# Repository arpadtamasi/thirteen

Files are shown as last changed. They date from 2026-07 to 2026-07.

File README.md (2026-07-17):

# thirteen

**A keyboard has 104 keys. When agents do the typing, you need thirteen:
status, approval, direction.**

An open-source, firmware-agnostic agent macropad: 13 mechanical keys, a
rotary encoder, a joystick, and per-key RGB that shows what your AI agents
are doing right now — thinking, running, waiting for you, done. Press a key
to approve. Flick the stick to steer.

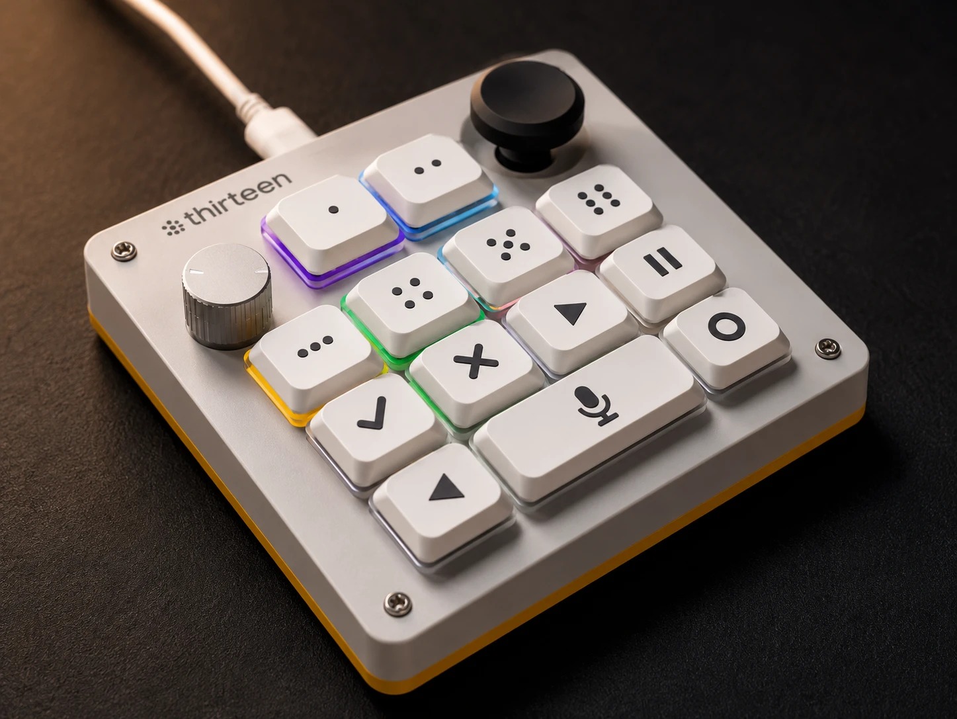
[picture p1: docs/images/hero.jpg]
thirteen — white colorway concept render


*AI-generated concept render of the actual design in this repo — key LEDs
in the daemon's default state colors: violet = thinking, blue = running,
amber = waiting, green = done; the edge ring glows with whichever agent
needs attention most. No physical build yet — the raw CAD geometry it's
based on is in [docs/images/cad-assembled-white.png](docs/images/cad-assembled-white.png),
rendered straight from `hardware/case/thirteen_case.scad`.*

## Why

OpenAI and Work Louder make a lovely version of this idea, the
[Codex Micro](https://openai.com/supply/co-lab/work-louder/): 13 keys,
encoder, joystick, $230 — and its agent features only work with one
vendor's desktop app.

thirteen is the DIY answer:

| | Codex Micro | thirteen |
|---|---|---|
| price | $230 | ~€30 in parts |
| keys / encoder / joystick | 13 / yes / yes | 13 / yes / yes |
| per-key RGB agent status | yes | yes |
| works with | Codex via ChatGPT desktop | anything (adapter pattern) |
| firmware | closed | this repo |
| case | CNC polycarbonate + aluminium | your 3D printer |

The core design principle: **the hardware knows nothing about any specific
agent.** The device is a plain USB HID keyboard plus a serial port speaking
newline-delimited JSON. All intelligence lives in a host-side daemon with
swappable adapters — Claude Code today, anything tomorrow, no reflash.

## Architecture

```
┌────────────┐ hooks  ┌──────────────────────┐   NDJSON    ┌──────────────┐
│ Claude Code├───────▶│                      │ over serial │   thirteen   │
└────────────┘        │    thirteen-host     │   115200 8N1 │  (ESP32-S3)  │
┌────────────┐ NDJSON │                      │             │              │
│ anything   ├───────▶│  adapters ──┐        │──── LEDs ──▶│ 19× SK6812   │
│ (stdin)    │        │  claude_code│ daemon │             │ 13× Choc     │
└────────────┘        │  generic_st…│  ────  │◀── events ──│ EC11 encoder │
┌────────────┐        │  demo      ─┘        │             │ 2-axis stick │
│ your agent ├───────▶│  config: one TOML    │             └──────┬───────┘
└────────────┘        └──────────────────────┘                    │ USB HID
                                                                  ▼
                                                        keystrokes (F13–F24)
                                                        straight to the OS
```

Two independent paths, by design:

- **Status path** (needs the daemon): adapter sees agent activity → daemon
  maps agent→key → LED shows state. Violet pulse = thinking, blue pulse =
  running, amber blink = **waiting for you**, green = done.
- **Action path** (works without any software): keys are a real HID
  keyboard typing F13–F24. Bind them in your terminal — approve, reject,
  interrupt — even if the daemon is down.

## Quickstart

**Have hardware?** Follow [docs/build-guide.md](docs/build-guide.md).
**Building from scratch?** [hardware/BOM.md](hardware/BOM.md) (~€30, with
shop links and a copy-paste [agent shopping prompt](hardware/BOM.md#agent-shopping-prompt)),
[hardware/WIRING.md](hardware/WIRING.md), printable case in
[hardware/case/](hardware/case/).

```sh
# 1. firmware (PlatformIO)
cd firmware && pio run -t upload && pio run -t uploadfs

# 2. host daemon
cd ../host && pip install -e .
cp config/thirteen.example.toml thirteen.toml   # set your port: /dev/ttyACM0 or COM3
thirteen-host

# 3. smoke test — a key should blink amber:
echo '{"agent_id":"hi","state":"waiting"}' | thirteen-host
```

Claude Code integration is a five-line hooks snippet:
[docs/adapter-guide.md](docs/adapter-guide.md). Key bindings, the voice
talk bar, and daily workflow: [docs/user-guide.md](docs/user-guide.md).

## Adapters

| adapter | drives it | status |
|---|---|---|
| `claude_code` | Claude Code hooks; multi-session, one key per session | ✅ shipped |
| `generic_stdin` | NDJSON on stdin — shell scripts, Codex CLI, n8n, CI | ✅ shipped |
| `demo` | nothing; cycles states for testing | ✅ shipped |
| yours | ~50 lines of Python: [docs/adapter-guide.md](docs/adapter-guide.md) | 🙋 PRs welcome |

## Repo map

```
firmware/   ESP32-S3 PlatformIO project (USB HID + CDC, LittleFS keymap)
protocol/   PROTOCOL.md — the NDJSON serial contract, versioned
host/       thirteen-host Python daemon + adapters
hardware/   BOM, wiring, parametric OpenSCAD case
docs/       build guide, user guide (bindings + voice), adapter guide
```

## Contributing

Small repo, sharp edges welcome — see [CONTRIBUTING.md](CONTRIBUTING.md).
Especially wanted: adapters for other agents, hw-test reports (grep for
`TODO(hw-test)`), case remixes.

## License

[MIT](LICENSE).

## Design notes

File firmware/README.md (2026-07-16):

# thirteen firmware

PlatformIO project for the ESP32-S3. Builds a USB composite device:
HID keyboard + CDC serial.

## Build & flash

```sh
pio run                          # build (default env: esp32-s3-devkitc-1)
pio run -t upload                # flash over USB
pio run -t uploadfs              # upload data/keymap.json to LittleFS
pio device monitor               # watch the NDJSON event stream
```

For an ESP32-S3 SuperMini board:

```sh
pio run -e supermini -t upload
```

The SuperMini has fewer pins broken out; its pin mapping lives in
`src/pins.h` behind the `SUPERMINI` define. Check it against your specific
board — SuperMini clones vary.

If the board doesn't enumerate after flashing, unplug/replug USB (switching
to the TinyUSB stack requires a cold restart of the USB connection).

## Layout

| file | what |
|---|---|
| `src/main.cpp`| entry point, serial protocol, HID output |
| `src/pins.h`  | GPIO assignment (both boards) |
| `src/input.*` | key debounce, EC11 decode, joystick gestures |
| `src/leds.*`  | SK6812 chain, solid/pulse/blink modes |
| `src/keymap.*`| LittleFS-persisted keymap, editable over serial  |
| `data/` | default keymap shipped to LittleFS via uploadfs  |

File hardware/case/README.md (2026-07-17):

# Case

Parametric OpenSCAD case: a top plate with Choc cutouts and a bottom shell
with a USB-C opening, screwed together with four M3 heat-set inserts.

## Export STLs

With [OpenSCAD](https://openscad.org/) installed:

```sh
openscad -D 'part="plate"' -o thirteen_plate.stl thirteen_case.scad
openscad -D 'part="shell"' -o thirteen_shell.stl thirteen_case.scad
```

Or in the GUI: open `thirteen_case.scad`, pick the part in the Customizer,
press F6 (render), then File → Export → STL.

## Render a preview image

`part="display"` is a non-printable assembled preview — keycaps with
legend icons (session dots 1-5, approve / reject / run / pause / stop,
prev / next / clear), encoder knob, thumbstick and per-key LED glow in
the daemon's default state colors. Render it in preview mode (no
`--render`, so colors show):

```sh
openscad -D 'part="display"' --imgsize=1920,1440 \
  --colorscheme='Tomorrow Night' --camera=51,46,8,45,0,318,240 \
  -o thirteen.png thirteen_case.scad
```

Options: `-D 'display_style="white"'` for the white colorway,
`-D show_icons=false` for blank caps.

## Print settings

- Plate: 0.2mm layers, 4+ perimeters, print flat, no supports. PETG or ABS
  preferred — Choc clips stress PLA over time.
- Shell: same, USB opening prints fine without supports at 45° bridging.
- Push M3 inserts into the shell bosses with a soldering iron at ~220°C.

## Tuning

Everything is a parameter at the top of the file. The ones you'll most
likely touch:

| parameter | default | change when |
|---|---|---|
| `switch_cutout` | 13.8 | your printer over/under-extrudes (try ±0.1) |
| `key_pitch_x/y` | 18.0 / 17.0 | using MX switches (19.05 / 19.05, cutout 14.0) |
| `shell_inner_height` | 13.0 | your wiring is tidier/messier than average |
| `usb_z` | 4.0 | your MCU sits at a different height — TODO(hw-test) |
| `joy_hole_d` | 24.0 | different joystick module |

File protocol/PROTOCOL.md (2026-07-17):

# thirteen serial protocol — v1

Newline-delimited JSON (NDJSON) over USB CDC serial, **115200 baud**, UTF-8.
One JSON object per line, terminated by `\n`. No line may exceed 1024 bytes
(a full `keymap_set` with text macros approaches this; keep macros short).

Every message carries a version field `"v": 1`. Receivers MUST ignore
messages with a higher major version than they support, and MUST ignore
unknown fields (forward compatibility).

Message type is in `"t"`.

## Transport

- The device enumerates as a USB composite device: HID keyboard + CDC serial.
- The HID interface types keystrokes directly (no host software needed for
  basic macro use). The CDC interface carries this protocol.
- On (re)connect the device sends `hello`. The host SHOULD wait for `hello`
  (or send `ping`) before assuming the link is up.

## Host → Device

### `ping`

```json
{"v": 1, "t": "ping"}
```

Device replies with `pong`.

### `led` — set the state of one key LED (or all)

```json
{"v": 1, "t": "led", "key": 4, "color": "#00FF88", "mode": "pulse"}
```

| field | type | notes |
|---|---|---|
| `key` | int | 0–12 = key LEDs, 13–18 = edge-glow segments, `-1` = every LED, `-2` = the edge ring as a group |
| `color` | string | `#RRGGBB` hex |
| `mode`  | string | `"solid"`, `"pulse"` (slow breathe), `"blink"` (hard on/off), `"off"` |

Device replies with `ack`.

### `keymap_set` — replace the stored keymap

```json
{"v": 1, "t": "keymap_set", "map": {"keys": [{"type": "key", "code": "F13"}, ...]}}
```

The `map` object is persisted to LittleFS (`/keymap.json`) and applied
immediately — no reflash required. See **Keymap format** below.
Device replies with `ack` (with `"ok": false` and an `"err"` string if the
map fails validation).

### `keymap_get` — read the current keymap

```json
{"v": 1, "t": "keymap_get"}
```

Device replies with `{"v": 1, "t": "keymap", "map": {...}}`.

## Device → Host

### `hello` — sent once on boot / USB reconnect

```json
{"v": 1, "t": "hello", "fw": "0.1.0", "proto": 1, "keys": 13, "edge": 6}
```

`edge` is the number of edge-glow LEDs after the key LEDs on the chain
(0 if the build has none).

### `key` — key press / release

```json
{"v": 1, "t": "key", "key": 7, "act": "down"}
```

`act` is `"down"` or `"up"`. Sent **in addition to** any HID output the
keymap produces for that key; keys mapped as `"none"` produce only this
event.

### `enc` — rotary encoder rotation

```json
{"v": 1, "t": "enc", "delta": 1}
```

`delta` is a signed integer: positive = clockwise. Multiple detents within
one poll interval are coalesced.

### `enc_btn` — encoder push

```json
{"v": 1, "t": "enc_btn", "act": "down"}
```

### `joy` — joystick gesture

```json
{"v": 1, "t": "joy", "dir": "up"}
```

`dir` is one of `"up"`, `"down"`, `"left"`, `"right"` (emitted once when the
stick leaves the deadzone in that direction; re-armed when it returns to
center) or `"press"` / `"release"` for the stick button.

### `ack`

```json
{"v": 1, "t": "ack", "of": "led", "ok": true}
{"v": 1, "t": "ack", "of": "keymap_set", "ok": false, "err": "bad key code"}
```

### `pong`

```json
{"v": 1, "t": "pong", "fw": "0.1.0", "proto": 1}
```

## Keymap format

The keymap is a JSON object stored on the device at `/keymap.json`:

```json
{
  "keys": [
    {"type": "key",  "code": "F13"},
    {"type": "key",  "code": "ENTER"},
    {"type": "text", "value": "yes\n"},
    {"type": "none"},
    ...13 entries total...
  ],
  "enc": {"cw": {"type": "key", "code": "VOL_UP"},
          "ccw": {"type": "key", "code": "VOL_DOWN"},
          "btn": {"type": "none"}}
}
```

Entry types:

| type | fields  | behaviour |
|---|---|---|
| `key`  | `code`  | sends a single HID keycode (see codes below) |
| `text` | `value` | types the string verbatim (`\n` allowed) |
| `none` | — | no HID output; the serial event is still emitted |

Recognised `code` values: `F1`–`F24`, `ENTER`, `ESC`, `TAB`, `SPACE`,
`BACKSPACE`, `UP`, `DOWN`, `LEFT`, `RIGHT`, `PAGE_UP`, `PAGE_DOWN`,
`VOL_UP`, `VOL_DOWN`, `MUTE`, and any single ASCII character (`"y"`, `"1"`).

`F13`–`F24` are the recommended defaults: real HID codes that no ordinary
keyboard emits, so they are safe to bind globally on the host side.

## Versioning

- `proto` in `hello`/`pong` is the protocol major version implemented by the
  firmware.
- Additive changes (new fields, new message types) do not bump the version.
- Breaking changes bump `v`/`proto`; a host seeing a higher `proto` than it
  knows SHOULD warn and fall back to `ping`/`key` events only.

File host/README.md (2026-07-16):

# thirteen-host

Python daemon that bridges the thirteen macropad to your agents.

```sh
pip install -e .                 # from this directory
cp config/thirteen.example.toml thirteen.toml
# edit thirteen.toml: set your serial port (/dev/ttyACM0, COM3, ...)
thirteen-host
```

Quick LED test without any agent: enable `[adapters.demo]` in the config
and watch the bottom row cycle through the state colors.

Quick test from a shell (generic_stdin adapter):

```sh
echo '{"agent_id":"hello","state":"waiting"}' | thirteen-host
```

Claude Code integration: install the `thirteen-hook` script into your hooks
(see `docs/adapter-guide.md`), then just use Claude Code — each session
claims a key and its LED tracks thinking / running / waiting / done.

Run tests:

```sh
pip install -e .[dev]
pytest
```

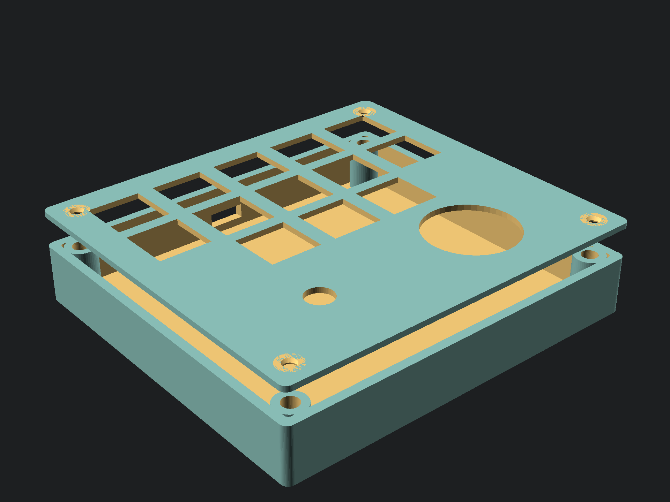
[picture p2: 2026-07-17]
docs/images/case-render.png

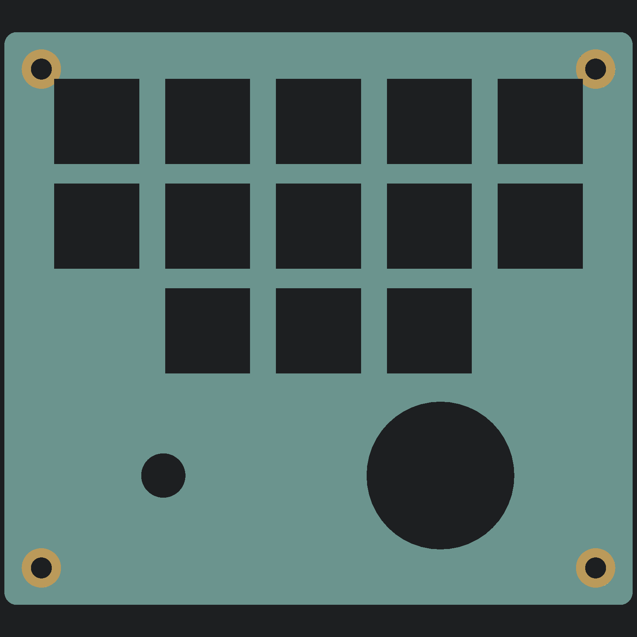
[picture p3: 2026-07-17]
docs/images/case-plate-top.png

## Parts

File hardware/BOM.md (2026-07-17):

# Bill of materials

Rough EU street prices, July 2026. Total lands around **€30** — roughly an
eighth of a Codex Micro, plus you own the firmware.

| # | part | qty | ~price (EU) | notes |
|---|---|-----|---|---|
| 1 | ESP32-S3 SuperMini | 1 | €5–8 | The tiny (~22×18mm) S3 board. Any ESP32-S3 board with native USB works; the DevKitC-1 is the firmware's default env. |
| 2 | Kailh Choc v1 switch | 13 | €6–9 | Low-profile, hot-swappable feel without a hotswap socket if you solder direct. Pick your weight; linear "Red Pro" (35g) suits rapid approvals. |
| 3 | Choc keycaps (MBK or similar) | 12× 1u + 1× 2u | €5–8 | The 2u goes on the talk bar (no stabilizer needed at this size). Or 3D-print them. One contrasting cap for the "approve" key is worth it. |
| 4 | SK6812 MINI-E RGB LED | 19 | €3–5 | 13 under the keys + 6 for the edge-glow ring. The MINI-E's legs stick out sideways — hand-solderable. Buy spares; they don't love hot-air rework. |
| 5 | EC11 rotary encoder (with push) | 1 | €1–2 | 15mm shaft + a knob you like. |
| 6 | 2-axis analog joystick module | 1 | €1–3 | KY-023-style thumbstick module with X/Y pots and a push switch. |
| 7 | M3 heat-set inserts | 4–6 | €1 | For the case; M3×5×4 short type. |
| 8 | M3×8 screws | 4–6 | €0.50 | |
| 9 | Hookup wire (30 AWG) | — | €2 | Handwired build: no PCB needed. |
| 10 | USB-C cable | 1 | — | You have one. |

**Total: ~€25–35**

Typical EU sources: splitkb.com, mykeyboard.eu, keycapsss.com (switches,
caps, LEDs); any electronics distributor or marketplace for the rest.

## Substitutions

- **MX switches instead of Choc**: fine — enlarge the plate cutouts to
  14.0mm and the switch spacing to 19.05mm in the OpenSCAD parameters.
- **SK6812 MINI (not -E) or WS2812B 3535**: same protocol, harder to
  hand-solder (pads under the body).
- **PSP-style joystick**: works, needs its own breakout and mounting tweak.
- **ESP32-S3-DevKitC-1**: bigger, but has all pins and is the default
  firmware env. Case is sized for the SuperMini; adjust `mcu_*` parameters.

## Where to buy

Direct product pages (EU-friendly):

- Kailh Choc v1 switches: [splitkb.com](https://splitkb.com/products/kailh-low-profile-choc-switches)
- MBK Choc keycaps: [fkcaps.com](https://fkcaps.com/keycaps/mbk), [splitkb.com keycaps](https://splitkb.com/collections/switches-and-keycaps)
- SK6812 MINI-E: [splitkb.com](https://splitkb.com/products/sk6812mini-e-rgb-leds), [keycapsss.com](https://keycapsss.com/keyboard-parts/parts/114/sk6812-mini-e-rgb-smd-led)
- ESP32-S3 SuperMini, EC11, joystick module, inserts, screws, wire:
  any electronics marketplace or distributor — search "ESP32-S3 SuperMini",
  "EC11 rotary encoder", "KY-023 joystick", "M3 heat-set insert".

## Agent shopping prompt

Copy-paste this into any AI assistant with web browsing and let it fill
your cart. The three classic ordering mistakes (Choc v2, RGBW LEDs, an
ESP32-**C3** instead of S3) are guarded against in the item notes.

```text
Help me buy the parts for a DIY macropad
(project: https://github.com/arpadtamasi/thirteen).
I'm in the EU — prefer EU shops for the keyboard parts (splitkb.com,
mykeyboard.eu, keycapsss.com); a marketplace like AliExpress is fine for
the generic electronics. Target total: EUR 25-40. For each item find the
exact product page, check stock, and give me the final cart list with
prices and shipping.

1. Kailh Choc v1 low-profile switches, LINEAR, ~35-50g — qty 13
   (must be Choc v1 / PG1350, NOT Choc v2, NOT KS-33)
2. MBK-profile Choc keycaps, blank — qty 12 in 1u plus ONE 2u (for the
   talk bar), any dark color + 1 accent color if available (must be
   Choc v1 stem, NOT MX)
3. SK6812 MINI-E RGB LEDs — qty 25 (19 + spares).
   CRITICAL: the RGB version, NOT the RGBW variant, and MINI-E (with side
   legs), not the plain MINI.
4. ESP32-S3 SuperMini dev board — qty 1. Must be ESP32-S3 (not C3/C6/H2!),
   USB-C, with native USB. Prefer a listing that shows the pinout diagram.
5. EC11 rotary encoder with push button, 15-20mm shaft — qty 1, plus one
   knurled aluminum knob for 6mm D-shaft
6. Dual-axis analog thumb joystick module (KY-023 style, 2 pots + switch,
   5-pin) — qty 1
7. M3 heat-set threaded inserts, M3x5mm, OD ~4.5mm — qty 10 (need 6)
8. M3x8mm socket head screws — qty 10
9. 30 AWG silicone-insulated hookup wire, 3+ colors — 1 small spool set

Flag anything where the listing is ambiguous about the variant (especially
items 1, 3, 4) instead of guessing.
```

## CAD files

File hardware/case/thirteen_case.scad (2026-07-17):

// thirteen — parametric case
// Top plate with Kailh Choc v1 cutouts + bottom shell with USB-C opening.
//
// Layout: encoder knob top-left, joystick top-right, two keys between
// them, then rows of 4 / 4 / 3 keys (13 keys total). An optional
// translucent bottom rim acts as a diffuser for the 6 edge-glow LEDs.
//
// Render:  set `part` below (or via -D on the CLI), F6, export STL.
// See README.md in this directory for exact commands.

/* [What to render] */
// "display" is a non-printable assembled preview with keycaps, knob,
// stick and LED glow — for renders only (use preview mode, F5/no --render,
// so the colors show).
part = "plate"; // ["plate", "shell", "both", "display"]

/* [Layout] */
// Choc spacing (MX: 19.05 x 19.05)
key_pitch_x = 18.0;
key_pitch_y = 17.0;
// Choc plate cutout (MX: 14.0). 13.8 per Kailh spec.
switch_cutout = 13.8;
// width reserved for the knob / joystick corner cells in the top band
corner_cell = 24.0;
// height of the top band (knob + joystick + 2 keys)
top_band = 28.0;

/* [Encoder + joystick] */
// EC11 shaft hole
enc_hole_d = 7.2;
// joystick module opening (stick clearance)
joy_hole_d = 24.0;

/* [Plate] */
plate_thickness = 1.5;   // Choc switches clip into 1.3-1.6mm
margin = 6.0;            // plate border around the key block

/* [Shell] */
wall = 2.4;
shell_inner_height = 13.0;  // room for handwiring + MCU
floor_thickness = 2.0;
// USB-C opening (plug body clearance)
usb_w = 9.6;
usb_h = 3.8;
// vertical offset of USB opening center above the inner floor —
// tune to where your MCU sits. TODO(hw-test): verify with your standoff.
usb_z = 4.0;

/* [Screws] */
insert_d = 4.2;          // M3 heat-set insert hole
insert_boss_d = 8.0;
screw_clearance_d = 3.4;

/* [Hidden] */
$fn = 48;
eps = 0.01;

// ---- derived dimensions -----------------------------------------------------

// top band: corner cell + 2 keys + corner cell
plate_w = 2 * corner_cell + 2 * key_pitch_x + 2 * margin;
plate_h = top_band + 3 * key_pitch_y + 2 * margin;

top_cy   = plate_h - margin - top_band / 2;   // knob / joystick / K0-K1 center
rows_top = plate_h - margin - top_band;       // top edge of the 4/4/3 block

enc_cx = margin + corner_cell / 2;            // knob, top-left
joy_cx = plate_w - margin - corner_cell / 2;  // joystick, top-right

// rows below the top band: 4 keys, 4 keys, then 1u + 2u talk bar + 1u

// screw bosses, inset from the four corners
boss_inset = margin;
boss_pos = [
    [boss_inset, boss_inset],
    [plate_w - boss_inset, boss_inset],
    [boss_inset, plate_h - boss_inset],
    [plate_w - boss_inset, plate_h - boss_inset],
];

// ---- key positions -----------------------------------------------------------

// key index -> [x, y] center. K0-K1 sit in the top band between knob and
// joystick; K2-K12 fill the 4/4/3 rows below.
function key_pos(i) =
    i < 2 ? [margin + corner_cell + (i + 0.5) * key_pitch_x, top_cy]
  : i < 10 ? let(j = i - 2,
        r = j < 4 ? 0 : 1,
        c = r == 0 ? j : j - 4,
        x0 = (plate_w - 4 * key_pitch_x) / 2)
    [x0 + (c + 0.5) * key_pitch_x,
     rows_top - r * key_pitch_y - key_pitch_y / 2]
    // bottom row: 1u, 2u talk bar, 1u (cells 18 / 36 / 18)
  : let(x0 = (plate_w - 4 * key_pitch_x) / 2,
        cx = i == 10 ? 0.5 * key_pitch_x
           : i == 11 ? 2.0 * key_pitch_x
           : 3.5 * key_pitch_x)
    [x0 + cx, rows_top - 2 * key_pitch_y - key_pitch_y / 2];

module at_each_key() {
    for (i = [0 : 12]) translate(key_pos(i)) children();
}

// ---- plate --------------------------------------------------------------------

module plate() {
    difference() {
        // plate slab
        linear_extrude(plate_thickness)
            offset(r = 2) offset(r = -2)  // rounded corners
                square([plate_w, plate_h]);

        // switch cutouts
        at_each_key()
            translate([-switch_cutout / 2, -switch_cutout / 2, -eps])
                cube([switch_cutout, switch_cutout, plate_thickness + 2 * eps]);

        // encoder shaft
        translate([enc_cx, top_cy, -eps])
            cylinder(d = enc_hole_d, h = plate_thickness + 2 * eps);

        // joystick opening
        translate([joy_cx, top_cy, -eps])
            cylinder(d = joy_hole_d, h = plate_thickness + 2 * eps);

        // corner screw holes (countersunk from top)
        for (p = boss_pos)
            translate([p[0], p[1], -eps]) {
                cylinder(d = screw_clearance_d, h = plate_thickness + 2 * eps);
                translate([0, 0, plate_thickness - 1.2])
                    cylinder(d1 = screw_clearance_d, d2 = 6.4, h = 1.2 + eps);
            }
    }
}

// ---- bottom shell ---------------------------------------------------------------

module shell() {
    total_h = floor_thickness + shell_inner_height;
    difference() {
        // outer body
        linear_extrude(total_h)
            offset(r = 2) offset(r = -2)
                square([plate_w, plate_h]);

        // inner cavity
        translate([wall, wall, floor_thickness])
            linear_extrude(total_h)
                offset(r = 1) offset(r = -1)
                    square([plate_w - 2 * wall, plate_h - 2 * wall]);

        // USB-C opening, centered on the top edge (MCU mounts against it)
        translate([plate_w / 2 - usb_w / 2,
                   plate_h - wall - eps,
                   floor_thickness + usb_z - usb_h / 2])
            cube([usb_w, wall + 2 * eps, usb_h]);
    }

    // heat-set insert bosses
    for (p = boss_pos)
        translate([p[0], p[1], 0])
            difference() {
                cylinder(d = insert_boss_d, h = total_h);
                translate([0, 0, total_h - 6])
                    cylinder(d = insert_d, h = 6 + eps);
            }
}

// ---- display assembly (render-only, not printable) -----------------------------

/* [Display options] */
display_style = "black"; // ["black", "white"]
show_icons = true;
// edge-glow color shown in the preview (the daemon paints it with the
// highest-priority agent state); "" = off
edge_glow = "#FFB000";

// per-key LED glow colors for the preview: the daemon's default state
// palette. "" = LED off. K0-K5 are the six agent keys.
glow_colors = [
    "#8A2BE2", "#00A0FF",                       // K0-K1, top band
    "#FFB000", "#00C853", "#8A2BE2", "",        // K2-K5, agent row
    "", "", "", "",                             // K6-K9, command row
    "", "", ""                                  // K10-K12, bottom row
];

case_color = display_style == "white" ? [0.90, 0.90, 0.91] : [0.13, 0.13, 0.14];
cap_color  = display_style == "white" ? [0.96, 0.96, 0.97] : [0.17, 0.17, 0.18];
icon_color = display_style == "white" ? [0.30, 0.30, 0.34] : [0.80, 0.80, 0.84];

// keycap legends: session dots 1-6 on the agent keys (top band + second
// row), then approve / reject / run / pause, then prev / next / clear
// bottom row: prev / push-to-talk bar / clear
icon_ids = ["d1", "d2",
            "d3", "d4", "d5", "d6",
            "chk", "x", "play", "pause",
            "left", "mic", "ring"];

module rounded_sq(w, h, r) {
    offset(r = r) offset(r = -r) square([w, h], center = true);
}

// MBK-ish Choc keycap; u = width in key units (2 = the talk bar)
module keycap(u = 1) {
    w = 16.9 + (u - 1) * 18;
    hull() {
        linear_extrude(0.01) rounded_sq(w, 15.9, 2);
        translate([0, 0, 3.2])
            linear_extrude(0.01) rounded_sq(w - 2.4, 13.5, 3);
    }
}

// knurled aluminum encoder knob
module knob() {
    color([0.72, 0.73, 0.76]) {
        cylinder(d = 13, h = 9);
        for (i = [0 : 23])
            rotate([0, 0, i * 15])
                translate([6.5, 0, 0.8]) cube([0.5, 0.8, 7.5], center = true);
    }
}

// thumbstick: shaft + flat rubber cap
module stick() {
    color([0.10, 0.10, 0.11]) {
        cylinder(d = 9, h = 7);
        translate([0, 0, 7]) cylinder(d = 20, h = 3.5);
        translate([0, 0, 10.5])
            cylinder(d1 = 20, d2 = 16, h = 1.2);
    }
}

// ---- keycap icons (2D, built from primitives — no font dependency) ---------

module seg(a, b, w) {
    hull() {
        translate(a) circle(d = w);
        translate(b) circle(d = w);
    }
}

module dots(n) {
    p = n == 1 ? [[0, 0]]
      : n == 2 ? [[-1.8, 0], [1.8, 0]]
      : n == 3 ? [[-2.4, 0], [0, 0], [2.4, 0]]
      : n == 4 ? [[-1.8, -1.8], [1.8, -1.8], [-1.8, 1.8], [1.8, 1.8]]
      : n == 5 ? [[-2, -2], [2, -2], [0, 0], [-2, 2], [2, 2]]
      :          [[-1.8, -2.2], [1.8, -2.2], [-1.8, 0], [1.8, 0],
                  [-1.8, 2.2], [1.8, 2.2]];
    for (q = p) translate(q) circle(d = 1.7);
}
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

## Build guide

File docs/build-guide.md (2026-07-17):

# Build guide

From parts bag to glowing keys. Budget an evening.

## 0. Before you solder

Flash the firmware first and test the bare board:

```sh
cd firmware
pio run -t upload            # DevKitC-1; add `-e supermini` for SuperMini
pio run -t uploadfs          # ship the default keymap to LittleFS
pio device monitor
```

You should see the `hello` line:

```json
{"t":"hello","fw":"0.1.0","proto":1,"keys":13,"edge":6,"v":1}
```

Short any key GPIO (see `hardware/WIRING.md`) to GND with a jumper — a
`key` event should appear and the board should type F13-ish keys into your
editor. If that works, everything electrical that follows is just
repetition.

If the board doesn't enumerate: hold BOOT while plugging in to enter the
ROM bootloader, flash, then unplug/replug.

## 1. Print the case

`hardware/case/README.md`. Print the plate first and test-fit one switch —
Choc clips should snap in firmly. Adjust `switch_cutout` ±0.1mm if not.

## 2. Solder, in this order

The LEDs live under the switches, so the order matters:

1. **LED chain first.** Place the 13 SK6812 MINI-E under each key position
   (legs sideways, hand-solderable). Chain them K0→K12: DOUT of each to DIN
   of the next, then continue the chain into the 6 edge-glow LEDs around
   the shell perimeter (indexes 13-18; skip them if you don't want the
   glowing rim — everything else still works). Common 5V and GND rails
   along the rows.
   Check the chain NOW — power the board and run:

   ```sh
   printf '{"v":1,"t":"led","key":-1,"color":"#220022","mode":"solid"}\n' > /dev/ttyACM0
   ```

   (Windows: use the host daemon or a serial terminal on COM3 instead.)
   All 19 LEDs should light. A dead LED mid-chain kills everything after
   it — fix now, not after the switches are in.

2. **Switches into the plate**, then one leg of each switch to its GPIO
   (30 AWG), the other legs daisy-chained to GND. No diodes — every key has
   its own pin.

3. **Encoder and joystick** into the top band (knob left, stick right);
   A/B/SW and X/Y/SW wires
   per the wiring table. Power the joystick from **3.3V** (its pots feed
   ADC pins that are not 5V-tolerant).

4. **Controller** on standoffs or a dab of double-sided foam against the
   shell's USB opening.

## 3. Close it up

M3 inserts into the shell bosses (soldering iron, ~220°C), plate on top,
four M3×8 screws. Keycaps on.

## 4. First run

```sh
cd host
pip install -e .
cp config/thirteen.example.toml thirteen.toml
# edit thirteen.toml -> serial port: /dev/ttyACM0 (Linux),
#                       /dev/cu.usbmodem* (macOS), COM3 (Windows)
thirteen-host
```

Sanity checks, in escalating order of satisfaction:

1. Enable `[adapters.demo]` in the config → bottom-row LEDs cycle colors.
2. `echo '{"agent_id":"me","state":"waiting"}' | thirteen-host` → a key
   blinks amber.
3. Wire up Claude Code hooks (`docs/adapter-guide.md`) → start a session,
   watch its key pulse violet while it thinks, blink amber when it wants
   approval, go green when done.

Then set up your key bindings and the voice talk bar:
[user-guide.md](user-guide.md).

## 5. Remapping keys

No reflash needed — the keymap lives on the device's flash filesystem and
is editable over serial. Example, make key 12 type "y\n" (approve):

```sh
python3 - <<'EOF'
import json, serial
port = "/dev/ttyACM0"           # or COM3
s = serial.Serial(port, 115200, timeout=2)
s.write(b'{"v":1,"t":"keymap_get"}\n')
km = json.loads(s.readline())["map"]
km["keys"][12] = {"type": "text", "value": "y\n"}
s.write((json.dumps({"v":1,"t":"keymap_set","map":km}) + "\n").encode())
print(s.readline().decode())    # ack
EOF
```

## Troubleshooting

| symptom | try |
|---|-----|
| no serial port appears | different cable (data lines!), unplug/replug after first flash |
| LEDs flicker / first LED wrong color | shorten the data wire to LED 0; power chain from 3.3V; check GRB vs RGB order in `leds.cpp` |
| joystick fires ghost directions | raise `JOY_TRIGGER` in `input.cpp`; cheap modules sit off-center — TODO(hw-test) center calibration is on the roadmap |
| encoder skips detents | swap A/B pins in `pins.h`, or your EC11 is half-step — halve the accumulator threshold in `input.cpp` |
| keys double-fire | raise `DEBOUNCE_MS` in `input.cpp` (5 → 8) |

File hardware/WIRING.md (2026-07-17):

# Wiring

Handwired, no PCB, no matrix, no diodes: 13 switches each go straight to a
GPIO (internal pull-up) and to a shared ground. The SK6812 LEDs form one
data chain. Everything runs off USB 5V; GPIO logic is 3.3V.

SK6812 note: the chain wants 5V supply, and its data-in officially wants
0.7×VDD = 3.5V — in practice 3.3V data into the first LED works reliably at
this scale. If your first LED glitches, power the chain from 3.3V instead,
or put a single 1N4148 in series with the 5V feed to drop it.

## GPIO assignment — ESP32-S3-DevKitC-1 (default firmware env)

| signal | GPIO | notes |
|---|---|---|
| K0–K1 (top band) + K2–K4 | 4, 5, 6, 7, 15 | switch → GPIO, other leg → GND |
| K5 + K6–K9 (command row) | 16, 17, 18, 21, 38 | |
| K10–K12 (bottom row, K11 = talk bar) | 39, 40, 41 | |
| LED data | 47 | → DIN of first SK6812; chain: 13 key LEDs, then 6 edge LEDs |
| Encoder A | 1 | EC11 A |
| Encoder B | 2 | EC11 B |
| Encoder push | 42 | EC11 switch pins |
| Joystick X | 9 | ADC1_CH8, module VRx |
| Joystick Y | 10 | ADC1_CH9, module VRy |
| Joystick push | 11 | module SW |

Strapping pins (0, 3, 45, 46) and octal-PSRAM pins (35–37) are deliberately
unused.

## GPIO assignment — ESP32-S3 SuperMini (`-e supermini`)

| signal | GPIO |
|---|---|
| K0–K4 | 1, 2, 3, 4, 5 |
| K5–K9 | 6, 7, 8, 9, 10 |
| K10–K12 | 11, 12, 13 |
| LED data | 14 |
| Encoder A / B / push | 21 / 47 / 48 |
| Joystick X / Y / push | 15 / 16 / 17 |

TODO(hw-test): SuperMini clones differ in which pins reach the headers —
verify against your board before soldering, and adjust `firmware/src/pins.h`
if needed.

## ASCII wiring diagram

```
                      ESP32-S3
                 ┌───────────────┐
   USB-C ═══════▶│ USB D+/D-     │
                 │               │
  K0 ─┬─ GPIO4   │               │   GPIO47 ──▶ DIN ┌──────┐DOUT
  K1 ─┼─ GPIO5   │               │                  │SK6812│──▶ ...19 LEDs,
  ... ┼          │  13 direct    │                  │ #0   │    one under
 K12 ─┴─ GPIO41  │  GPIOs, all   │                  └──────┘    each key
   │             │  INPUT_PULLUP │                   5V│ │GND
  GND (shared)   │               │
                 │               │        EC11        joystick
                 │        GPIO1 ─┼──────── A          module
                 │        GPIO2 ─┼──────── B          ┌─────┐
                 │       GPIO42 ─┼──────── SW    ┌────┤ VRx │ GPIO9
                 │               │               │ ┌──┤ VRy │ GPIO10
                 │        GPIO9 ─┼───────────────┘ │  │ SW  │ GPIO11
                 │       GPIO10 ─┼─────────────────┘  │ 5V* │
                 │       GPIO11 ─┼────────────────────┤ GND │
                 └───────────────┘                    └─────┘

  * power the joystick module from 3.3V, not 5V — its pots feed the ADC
    directly and the S3's ADC pins are not 5V-tolerant.

  Switch wiring:  GPIO ──[switch]── GND      (no diode needed: one pin
                                              per key, nothing to ghost)
  LED chain:      5V ──┬── all SK6812 VDD
                  GND ─┴── all SK6812 GND    data chained K0→K12,
                                              then 6 edge LEDs
```

## Joystick module footprint

TODO(hw-test): a KY-023 breakout board (~26×34mm) is larger than the
top-right corner it mounts under. Options: rotate the board diagonally,
trim its corners, or desolder the stick and mount it bare on perfboard.
The plate opening only cares about the stick itself (24mm clearance).

## LED chain order

19 LEDs on one chain: key LEDs K0→K12 first (indexes 0–12), then the six
edge-glow LEDs (indexes 13–18) mounted face-down or face-out around the
shell perimeter, shining into the translucent bottom rim. Print the shell
(or just its bottom band) in translucent filament to get the diffused
edge glow; skip the 6 LEDs entirely and the pad still works — the ring
just stays dark.

## Soldering order

See `docs/build-guide.md` — LEDs first (they sit under the switches), then
switches, then the controller.

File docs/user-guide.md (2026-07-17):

# User guide

What every control does, how to wire the keys into your OS, and how to
talk to your agents through the pad. For assembly see
[build-guide.md](build-guide.md); for writing adapters see
[adapter-guide.md](adapter-guide.md).

## The controls

```
 ┌────────────────────────────────┐
 │ (knob)   [•] [••]   (joystick) │   top band
 │   [•3] [•4] [•5] [•6]          │   agent keys 3-6
 │   [✓]  [✗]  [▶]  [⏸]           │   command row
 │   [◀] [   🎤 talk   ] [○]      │   bottom row
 └────────────────────────────────┘
        edge-glow rim all around
```

| control | index | default HID output | intended use |
|---|---|---|---|
| agent keys | K0–K5 | F13–F18 | one per agent session; LED = its state, press = act on it |
| ✓ approve | K6 | F19 | approve / confirm |
| ✗ reject | K7 | F20 | reject / cancel |
| ▶ run | K8 | F21 | continue / resume |
| ⏸ pause | K9 | F22 | interrupt / stop |
| ◀ prev | K10 | F23 | previous item / undo-ish |
| 🎤 talk bar | K11 | F24 | push-to-talk → your dictation tool |
| ○ clear | K12 | none (serial only) | clears finished sessions (daemon binding) |
| encoder | — | volume up/down, push = mute | scroll history, or rebind |
| joystick | — | serial events only | direction: navigate; press: select |

Everything above is remappable: the HID side over serial
(`protocol/PROTOCOL.md`, no reflash), the action side in `thirteen.toml`.

## LED states

| color | mode | meaning |
|---|---|---|
| violet | pulse | agent is thinking |
| blue | pulse | agent is running tools |
| **amber** | **blink** | **agent is waiting for YOU** |
| green | solid | done |
| red | blink | error |

The translucent **edge rim** always shows the most attention-worthy state
across all agents (error > waiting > running > thinking > done) — the
"do I need to look?" signal that works from across the room.

## Wiring the keys into your OS

The pad types F13–F24 — real keycodes no normal keyboard emits, so you can
bind them globally without collisions. The daemon does **not** need to run
for any of this; it's plain USB keyboard input.

### Terminal (tmux) — the classic Claude Code setup

```tmux
# ~/.tmux.conf — approve / reject / continue / interrupt from the pad
bind-key -n F19 send-keys y Enter      # ✓
bind-key -n F20 send-keys n Enter      # ✗
bind-key -n F21 send-keys Enter        # ▶
bind-key -n F22 send-keys C-c          # ⏸
bind-key -n F13 select-window -t 1     # agent key 1 -> its window
bind-key -n F14 select-window -t 2     # agent key 2 -> its window
```

Run each Claude Code session in its own tmux window and the agent keys
become "jump to that session" buttons: amber key blinks → press it →
you're in that session → ✓ to approve.

### macOS

- System Settings → Keyboard → Keyboard Shortcuts → App Shortcuts, or a
  tool like Karabiner-Elements / BetterTouchTool / Raycast to bind
  F13–F24 to anything (scripts, window focus, menu items).
- iTerm2: Settings → Keys → Key Bindings → "Send Text" to map F19 → `y\n`
  directly in the terminal, no tmux needed.

### Windows

AutoHotkey v2 (`thirteen.ahk`, drop in `shell:startup`):

```ahk
F19::Send "y{Enter}"      ; approve
F20::Send "n{Enter}"      ; reject
F22::Send "^c"            ; interrupt
```

### Linux

Most desktop environments bind F13–F24 in Settings → Keyboard →
Custom Shortcuts. For window managers: `wtype`/`xdotool` in a script,
or bind in your terminal emulator / tmux as above.

## Voice: the talk bar 🎤

There is **no microphone in the pad** (same as the Codex Micro — its mic
key just triggers the ChatGPT app). The talk bar types **F24**; your
computer's dictation tool does the listening. Press the bar, speak, and
the text lands wherever your cursor is — e.g. the Claude Code prompt.

### macOS

Option A — built-in Dictation:
1. System Settings → Keyboard → Dictation → **on**.
2. Set *Shortcut* → Customize… → press the talk bar (registers as F24).
3. Talk bar → speak → text appears at the cursor. Press again to stop.

Option B — Whisper-based tools (better for code/technical terms):
Superwhisper, VoiceInk, MacWhisper all support a global toggle hotkey —
set it to F24. Push-to-talk mode in Superwhisper feels exactly like a
hardware mic bar.

### Windows

Built-in dictation sits on Win+H and can't be rebound directly — bridge
it with AutoHotkey v2:

```ahk
F24::Send "#h"   ; talk bar toggles Windows dictation
```

Whisper-based alternatives (e.g. Whisper Typing, Aiko-likes) accept a
custom hotkey — set F24 directly, no bridge needed.

### Linux

[nerd-dictation](https://github.com/ideasman42/nerd-dictation) (VOSK,
offline) with a toggle wrapper is the usual choice. Either bind F24 to
the toggle script in your DE's keyboard settings, or skip the keymap
entirely and let the daemon run it:

```toml
# thirteen.toml
[keys]
11 = { type = "shell", command = "nerd-dictation-toggle" }
```

(If you bind it in the daemon, consider remapping K11's HID output to
`none` over serial so F24 doesn't also fire.)

### The voice workflow

1. Amber key blinks — an agent wants something.
2. Press its agent key → your terminal focuses that session (tmux
   binding above).
3. Hold your answer? ✓ / ✗ is one press. Longer answer? Talk bar,
   speak, Enter.

## Everyday daemon usage

```sh
thirteen-host                 # foreground, ctrl-c to stop
thirteen-host -v              # verbose: see every event and LED command
thirteen-host -c work.toml    # alternate config
```

Run it however you run small daemons: a systemd user unit, a LaunchAgent,
or just a tmux pane. If it dies or you unplug the pad, keys keep typing
F13–F24 (HID needs no software) — only the status LEDs pause; the daemon
reconnects and repaints automatically.

Multiple Claude Code sessions: nothing to configure. Each session's hooks
report with its own `session_id`; the daemon gives each one a key from
the `claude_code` pool and frees it `done_timeout` seconds after the
session goes quiet. The ○ key clears all finished sessions immediately.

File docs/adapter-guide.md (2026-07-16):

# Writing an adapter

An adapter is the only thing that knows about your agent. The contract is
two methods and one callback — a useful adapter fits in ~50 lines.

## The contract

```python
from thirteen_host.adapters import Adapter

class MyAdapter(Adapter):
    name = "my_agent"                       # config table: [adapters.my_agent]

    async def run(self):
        """Long-running task. Watch your agent however you like and call
        self.emit(agent_id, state) whenever something changes."""

    async def handle_action(self, action, params):
        """Called when a key bound to this adapter is pressed (optional)."""
```

- `agent_id` is any stable string — a session id, a hostname, "build".
  The daemon assigns each agent_id a key from your `keys` pool and keeps
  the mapping stable while the agent is active.
- `state` is one of `idle`, `thinking`, `running`, `waiting`, `done`,
  `error`. Map whatever your agent reports onto these six; the LED color
  scheme is configured per state, not per adapter.

Register it in `create_adapters()` (`adapters/__init__.py`) and add a
`[adapters.my_agent]` table with a `keys = [...]` pool to the config.
That's the whole integration.

## A complete example (~40 lines)

An adapter that watches a directory of lock files — any process can
`touch /tmp/agents/<name>.running` (or `.waiting`, `.done`):

```python
import asyncio
from pathlib import Path
from thirteen_host.adapters import Adapter

class LockfileAdapter(Adapter):
    name = "lockfiles"

    async def run(self):
        watch = Path(self.config.get("path", "/tmp/agents")).expanduser()
        watch.mkdir(parents=True, exist_ok=True)
        known: dict[str, str] = {}
        while True:
            seen = {}
            for f in watch.glob("*.*"):
                agent, state = f.stem, f.suffix.lstrip(".")
                if state in ("thinking", "running", "waiting", "done", "error"):
                    seen[agent] = state
            for agent, state in seen.items():
                if known.get(agent) != state:
                    await self.emit(agent, state)
            for agent in known.keys() - seen.keys():
                await self.emit(agent, "idle")
            known = seen
            await asyncio.sleep(0.5)
```

## Ready-made adapters

### claude_code

Integrates via Claude Code hooks. Each hook run executes `thirteen-hook`
(installed with the package), which appends a status line to an events
file; the adapter tails it. Multi-session aware: every Claude Code session
claims its own key.

Add to your Claude Code `settings.json` (user-level `~/.claude/settings.json`
or per-project `.claude/settings.json`):

```json
{
  "hooks": {
    "UserPromptSubmit": [{ "hooks": [{ "type": "command", "command": "thirteen-hook" }] }],
    "PreToolUse":       [{ "hooks": [{ "type": "command", "command": "thirteen-hook" }] }],
    "PostToolUse":      [{ "hooks": [{ "type": "command", "command": "thirteen-hook" }] }],
    "Notification":     [{ "hooks": [{ "type": "command", "command": "thirteen-hook" }] }],
    "Stop":             [{ "hooks": [{ "type": "command", "command": "thirteen-hook" }] }]
  }
}
```

State mapping: `UserPromptSubmit`/`PostToolUse` → thinking, `PreToolUse` →
running, `Notification` → waiting (that's your amber "needs approval"
blink), `Stop` → done.

Approvals: the pad is a real HID keyboard typing F13–F24, so bind those in
your terminal multiplexer — e.g. tmux: `bind-key -n F13 send-keys y Enter`.
No host round-trip, works even if the daemon is down.

### generic_stdin

Pipe NDJSON to the daemon and you're integrated:

```sh
echo '{"agent_id":"deploy","state":"running"}' | thirteen-host
```

This is the escape hatch for everything else: Codex CLI wrappers, n8n HTTP
→ shell, CI scripts, cron jobs.

### demo

No agent at all — cycles the six states across its key pool so you can
check wiring and colors.

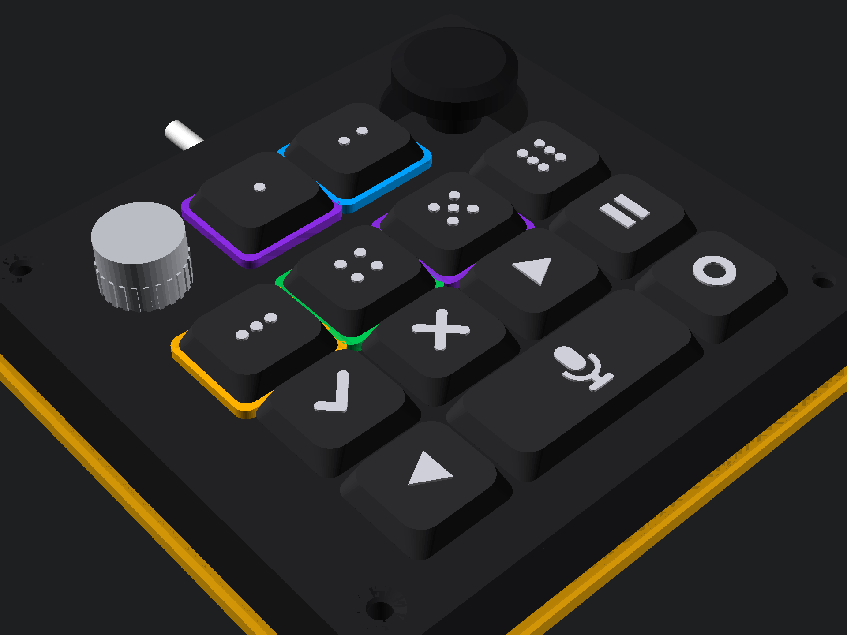
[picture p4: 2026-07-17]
docs/images/cad-assembled.png

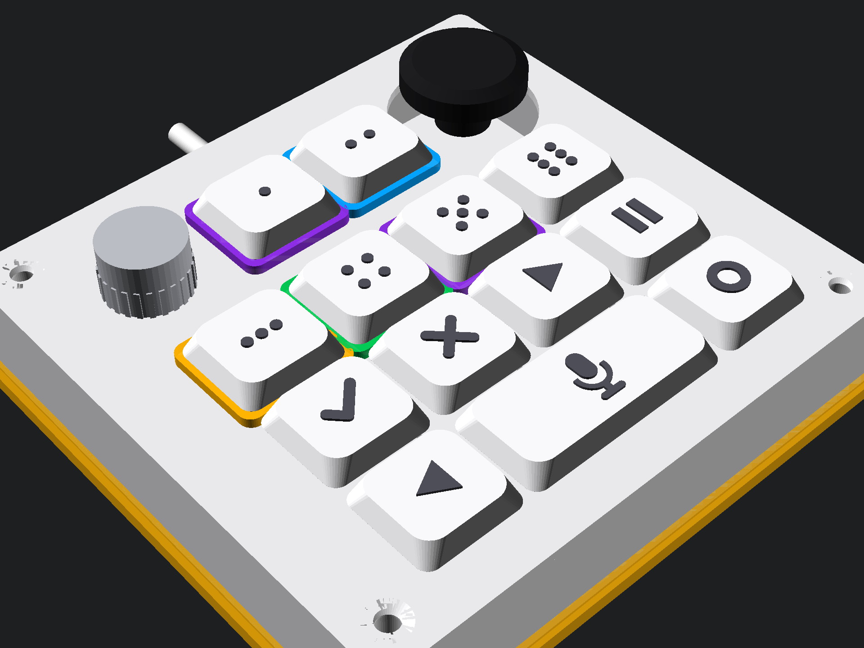
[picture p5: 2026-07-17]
docs/images/cad-assembled-white.png

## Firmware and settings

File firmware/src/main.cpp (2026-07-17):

// thirteen — firmware entry point.
//
// USB composite device: HID keyboard + CDC serial. Keys produce HID output
// according to the LittleFS keymap AND emit NDJSON events over CDC; the
// host daemon drives the per-key RGB LEDs. Protocol: protocol/PROTOCOL.md.

#include <Arduino.h>
#include <ArduinoJson.h>
#include <LittleFS.h>
#include <USB.h>
#include <USBHIDKeyboard.h>
#include <USBHIDConsumerControl.h>

#include "pins.h"
#include "keymap.h"
#include "leds.h"
#include "input.h"

#ifndef THIRTEEN_FW_VERSION
#define THIRTEEN_FW_VERSION "0.0.0-dev"
#endif
static constexpr int PROTO_VERSION = 1;

static USBHIDKeyboard Keyboard;
static USBHIDConsumerControl Consumer;

// ---- serial out ------------------------------------------------------------

static void sendJson(JsonDocument& doc) {
    doc["v"] = PROTO_VERSION;
    serializeJson(doc, Serial);
    Serial.print('\n');
}

static void sendHello() {
    JsonDocument doc;
    doc["t"] = "hello";
    doc["fw"] = THIRTEEN_FW_VERSION;
    doc["proto"] = PROTO_VERSION;
    doc["keys"] = NUM_KEYS;
    doc["edge"] = NUM_EDGE_LEDS;
    sendJson(doc);
}

static void sendAck(const char* of, const char* err = nullptr) {
    JsonDocument doc;
    doc["t"] = "ack";
    doc["of"] = of;
    doc["ok"] = (err == nullptr);
    if (err) doc["err"] = err;
    sendJson(doc);
}

static void sendKeyEvent(uint8_t key, bool down) {
    JsonDocument doc;
    doc["t"] = "key";
    doc["key"] = key;
    doc["act"] = down ? "down" : "up";
    sendJson(doc);
}

// ---- HID output ------------------------------------------------------------

static void hidPress(const KeyAction& a) {
    switch (a.type) {
        case ActionType::None:
            break;
        case ActionType::Key:
            if (a.consumer) {
                Consumer.press(a.consumer);
                Consumer.release();
            } else {
                Keyboard.press(a.hid);
            }
            break;
        case ActionType::Text:
            Keyboard.print(a.text);
            break;
    }
}

static void hidRelease(const KeyAction& a) {
    if (a.type == ActionType::Key && !a.consumer) Keyboard.release(a.hid);
}

static void hidTap(const KeyAction& a) {
    hidPress(a);
    hidRelease(a);
}

// ---- host -> device commands ------------------------------------------------

static uint32_t parseHexColor(const char* s) {
    if (!s || s[0] != '#' || strlen(s) != 7) return 0;
    return (uint32_t)strtoul(s + 1, nullptr, 16);
}

static void handleLine(char* line) {
    JsonDocument doc;
    if (deserializeJson(doc, line) != DeserializationError::Ok) return;
    const char* t = doc["t"] | "";

    if (strcmp(t, "ping") == 0) {
        JsonDocument out;
        out["t"] = "pong";
        out["fw"] = THIRTEEN_FW_VERSION;
        out["proto"] = PROTO_VERSION;
        sendJson(out);

    } else if (strcmp(t, "led") == 0) {
        int key = doc["key"] | -1;
        uint32_t rgb = parseHexColor(doc["color"] | "#000000");
        const char* m = doc["mode"] | "solid";
        LedMode mode = LedMode::Solid;
        if (strcmp(m, "pulse") == 0) mode = LedMode::Pulse;
        else if (strcmp(m, "blink") == 0) mode = LedMode::Blink;
        else if (strcmp(m, "off") == 0) mode = LedMode::Off;
        if (key >= NUM_LEDS || key < -2) {
            sendAck("led", "key out of range");
        } else {
            ledsSet(key, rgb, mode);
            sendAck("led");
        }

    } else if (strcmp(t, "keymap_set") == 0) {
        JsonObjectConst map = doc["map"];
        if (map.isNull()) {
            sendAck("keymap_set", "missing map");
        } else {
            const char* err = keymapApply(map);
            sendAck("keymap_set", err);
        }

    } else if (strcmp(t, "keymap_get") == 0) {
        JsonDocument out;
        out["t"] = "keymap";
        keymapSerialize(out["map"].to<JsonObject>());
        sendJson(out);
    }
    // unknown types are ignored (forward compatibility)
}

static void pollSerial() {
    static char buf[1024];  // must fit a full keymap_set line
    static size_t len = 0;
    while (Serial.available()) {
        char c = Serial.read();
        if (c == '\n') {
            buf[len] = 0;
            if (len > 0) handleLine(buf);
            len = 0;
        } else if (len < sizeof(buf) - 1) {
            buf[len++] = c;
        } else {
            len = 0;  // line too long: drop it
        }
    }
}

// ---- main ------------------------------------------------------------------

void setup() {
    Serial.begin(115200);
    Keyboard.begin();
    Consumer.begin();
    USB.begin();

    LittleFS.begin(true);  // format on first boot
    keymapInit();
    ledsInit();
    inputInit();

    // brief boot animation so a fresh build shows signs of life
    ledsSet(-1, 0x202020, LedMode::Pulse);

    delay(100);
    sendHello();
}

void loop() {
    InputEvents ev = inputPoll();

    for (uint8_t i = 0; i < NUM_KEYS; i++) {
        if (ev.down & (1u << i)) {
            hidPress(keymap.keys[i]);
            sendKeyEvent(i, true);
        }
        if (ev.up & (1u << i)) {
            hidRelease(keymap.keys[i]);
            sendKeyEvent(i, false);
        }
    }

    if (ev.encDelta != 0) {
        hidTap(ev.encDelta > 0 ? keymap.encCw : keymap.encCcw);
        JsonDocument doc;
        doc["t"] = "enc";
        doc["delta"] = ev.encDelta;
        sendJson(doc);
    }

    if (ev.encBtn != 0) {
        if (ev.encBtn > 0) hidPress(keymap.encBtn);
        else hidRelease(keymap.encBtn);
        JsonDocument doc;
        doc["t"] = "enc_btn";
        doc["act"] = ev.encBtn > 0 ? "down" : "up";
        sendJson(doc);
    }

    if (ev.joy != InputEvents::JoyNone) {
        static const char* dirs[] = {"", "up", "down", "left", "right",
                                     "press", "release"};
        JsonDocument doc;
        doc["t"] = "joy";
        doc["dir"] = dirs[ev.joy];
        sendJson(doc);
    }

    pollSerial();
    ledsTick();
}

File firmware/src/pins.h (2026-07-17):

#pragma once

// Pin assignment — ESP32-S3-DevKitC-1 (default) and SuperMini override.
// 13 keys on direct GPIO (internal pull-ups, switch to GND — no matrix,
// no diodes). See hardware/WIRING.md for the physical layout.

#include <cstdint>

constexpr uint8_t NUM_KEYS = 13;
// SK6812 chain: one LED per key (0-12), then the edge-glow ring LEDs
// around the case rim (13..). Edge LEDs are addressed via the protocol
// as indexes 13-18, or -2 for the whole ring.
constexpr uint8_t NUM_EDGE_LEDS = 6;
constexpr uint8_t NUM_LEDS = NUM_KEYS + NUM_EDGE_LEDS;

#ifdef SUPERMINI
// ESP32-S3 SuperMini: fewer pins broken out. GPIO 33-37 are not available
// (used by internal flash/PSRAM on most SuperMini modules); 43/44 are the
// UART0 pads. This mapping uses only pins present on the common SuperMini
// pinout. TODO(hw-test): verify against your specific SuperMini clone —
// pinouts vary between sellers.
constexpr uint8_t KEY_PINS[NUM_KEYS] = {
    1, 2, 3, 4, 5,        // K0-K1 top band, K2-K4 agent row
    6, 7, 8, 9, 10,       // K5 agent row, K6-K9 command row
    11, 12, 13            // K10-K12 bottom row (K11 = talk bar)
};
constexpr uint8_t PIN_LED_DATA = 14;   // SK6812 chain data-in
constexpr uint8_t PIN_ENC_A    = 21;
constexpr uint8_t PIN_ENC_B    = 47;
constexpr uint8_t PIN_ENC_SW   = 48;
constexpr uint8_t PIN_JOY_X    = 15;   // must be ADC-capable
constexpr uint8_t PIN_JOY_Y    = 16;   // must be ADC-capable
constexpr uint8_t PIN_JOY_SW   = 17;
#else
// ESP32-S3-DevKitC-1. Avoids strapping pins (0, 3, 45, 46) and the pins
// used by octal PSRAM on the N8R8 variant (35, 36, 37).
constexpr uint8_t KEY_PINS[NUM_KEYS] = {
    4, 5, 6, 7, 15,       // K0-K1 top band, K2-K4 agent row
    16, 17, 18, 21, 38,   // K5 agent row, K6-K9 command row
    39, 40, 41            // K10-K12 bottom row (K11 = talk bar)
};
constexpr uint8_t PIN_LED_DATA = 47;   // SK6812 chain data-in
constexpr uint8_t PIN_ENC_A    = 1;
constexpr uint8_t PIN_ENC_B    = 2;
constexpr uint8_t PIN_ENC_SW   = 42;
constexpr uint8_t PIN_JOY_X    = 9;    // ADC1_CH8
constexpr uint8_t PIN_JOY_Y    = 10;   // ADC1_CH9
constexpr uint8_t PIN_JOY_SW   = 11;
#endif

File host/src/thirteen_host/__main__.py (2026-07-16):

"""CLI entry point: `thirteen-host [-c CONFIG] [-v]`."""

from __future__ import annotations

import argparse
import asyncio
import logging
import sys
from pathlib import Path

from .config import load_config
from .daemon import Daemon


def main() -> None:
    parser = argparse.ArgumentParser(
        prog="thirteen-host",
        description="Host daemon for the thirteen agent macropad",
    )
    parser.add_argument("-c", "--config", type=Path, default=None,
                        help="path to thirteen.toml (default: ./thirteen.toml "
                             "or ~/.config/thirteen/thirteen.toml)")
    parser.add_argument("-v", "--verbose", action="store_true")
    args = parser.parse_args()

    logging.basicConfig(
        level=logging.DEBUG if args.verbose else logging.INFO,
        format="%(asctime)s %(name)s %(levelname)s %(message)s",
    )

    try:
        config = load_config(args.config)
    except (FileNotFoundError, ValueError) as e:
        print(f"error: {e}", file=sys.stderr)
        sys.exit(1)

    try:
        asyncio.run(Daemon(config).run())
    except KeyboardInterrupt:
        pass


if __name__ == "__main__":
    main()

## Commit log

2026-07-16 Scaffold thirteen: firmware, protocol, host daemon, hardware, docs
    Complete initial scaffold for the open-source, firmware-agnostic agent
    macropad — 13 keys, encoder, joystick, per-key RGB agent status.
    - firmware/: ESP32-S3 PlatformIO project (DevKitC-1 + SuperMini envs),
    USB HID keyboard + CDC composite, 13 direct-GPIO keys with integrating
    debounce, SK6812 chain via FastLED (solid/pulse/blink), EC11 quadrature
    decode, joystick flick gestures, LittleFS keymap editable over serial
    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
    [thirteen_case.scad]
2026-07-16 Add hero image to README
    AI-generated concept render of the assembled pad (to be replaced with a
    photo of a real build).
    Claude-Session: https://claude.ai/code/session_01UapcB2kioso1M8tPnkBJof
2026-07-17 Add shop links and agent shopping prompt to BOM
    Direct EU product pages for the fiddly parts (Choc v1 switches, MBK caps,
    SK6812 MINI-E) and a copy-paste prompt for browsing AI assistants that
    guards against the classic variant mistakes (Choc v2, RGBW, ESP32-C3).
    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
2026-07-17 Add OpenSCAD case renders
    Rendered straight from hardware/case/thirteen_case.scad — exploded
    assembly and top-down plate view verifying the 5/5/3 layout.
    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
2026-07-17 Use CAD render as README hero instead of AI concept image
    The OpenSCAD render is the actual buildable geometry; the concept render
    stays in docs/images for reference.
    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
2026-07-17 Add assembled display render to the case model
    New part="display" in thirteen_case.scad: non-printable preview with
    keycaps, knurled encoder knob, thumbstick, USB stub and per-key LED glow
    in the default state colors. Rendered image becomes the README hero;
    render command documented in hardware/case/README.md.
    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
    [thirteen_case.scad]
2026-07-17 Add keycap icons and white colorway to the display render
    Legends built from 2D primitives (no font dependency): session dots 1-5
    on the top row, approve/reject/run/pause/stop in the middle, prev/next/
    clear at the bottom. New display_style ("black"/"white") and show_icons
    parameters; README hero updated, white variant added alongside.
    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
    [thirteen_case.scad]
2026-07-17 Rework layout Codex-style and add edge-glow ring
    Layout: encoder knob top-left and joystick top-right integrated into the
    top band with two keys between them, then 4/4/3 rows — the bottom-middle
    key wears a 2u talk bar cap with a mic legend. Keys 0-5 form the six
    agent keys.
    Edge glow: 6 extra SK6812s after the key LEDs light a translucent bottom
    rim; protocol gains key indexes 13-18 and -2 for the ring, hello reports
    "edge". The daemon paints the ring with the highest-priority active
    state (error > waiting > running > thinking > done), toggleable via
    [edge] in the config. BOM, wiring and renders updated.
    Claude-Session: https://clau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
    [thirteen_case.scad]
2026-07-17 Document edge ring and new layout; update renders
    Protocol: led key indexes 13-18 / -2, hello "edge" field. Wiring: LED
    chain order and translucent rim note. BOM: 19 LEDs. Config example:
    [edge] section, new key index map, talk-bar binding hint. New renders.
    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
2026-07-17 Replace hero image with white-colorway concept render
    Photoreal AI render matching the actual CAD design (layout, icons, state
    colors, amber edge glow); caption links the underlying CAD render.
    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
2026-07-17 Fix stale references after the layout rework
    Keycap BOM is now 12x 1u + one 2u talk bar, the build guide and wiring
    diagram count all 19 chain LEDs, encoder/joystick moved to the top band
    in the soldering steps, and the KY-023 footprint caveat is documented.
    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
